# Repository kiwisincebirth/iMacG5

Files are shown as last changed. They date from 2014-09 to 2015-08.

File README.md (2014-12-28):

iMacG5
======

This is an Arduino (Leonardo) project that implements a System Management Controller on a Apple iMac that has been converted to a Hackintosh replacing the original G5 motherboard with an Intel Haswell NUC D54250. See the following for full details of the project:

http://www.tonymacx86.com/completed-mods/139633-kiwis-20-imac-i5.html

The software (and hardware) provide System management function including
 * Management of full power management lifecycle.
 * Control of shutdown of original G5 ATX PSU
 * Control of LCD backlight inverter brightness from Mac Menu widget
 * Control of screen Brightnes via Mac Menu application (via USB serial)
 * Fan Speed Control from internal temperature monitoring
 * Front Panel LED and Power Switch control

This repository contains
 * The full Bill of Materials for the Hardware
 * The source code for Arduino microcontroller
 * The source code for the Brightness Menu on the Mac

This application also has code to support capacative touch sensors as used by MacTester in his excellent iMac creations. Thanks for hs contribution to this project.

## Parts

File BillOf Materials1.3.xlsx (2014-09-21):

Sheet: Sheet1
DESCRIPTION
 | This is a BOM and design of SMC controller for iMac G5 20 innch conversion. See the following links
 | http://www.tonymacx86.com/completed-mods/139633-kiwis-20-imac-i5.html
 | http://www.tonymacx86.com/imac-mods/107859-kiwis-next-project-imac-g5.html
PARTS
 | ARDUINO MODULE
 |  | https://www.sparkfun.com/products/12640
 |  | The module also needs pins soldered to it so it can be inserted in the IC Socket
 |  | The 24 pin IC socket needs to be seperated into two halves as the module is wider than a standard 24 pin IC
 | SOUND MODULE
 |  | NOTE: The full ISD1820 Module is needed that includes the microphone to record the sound.
 |  | As the constructed board does not include the record capability. The chip must be programmed off board
 |  | The Sound Module must have the ISD Chip is a socket
 |  | An identical ROSC resistor must be installed on the Sound recorder module to achieve the same record speed
 | PAM 8403
 |  | This module can be purchased on eBay
 | HEATSINK
 |  | The heatsink also requires a TO220 Mounting kit that includes a mica flm, and plastic screw insert
 | TEMP SENSOR
 |  | http://datasheets.maximintegrated.com/en/ds/DS18B20.pdf
SOFTWARE
 | https://github.com/kiwisincebirth/iMacG5/tree/master/SourceCode/iMac_i5_Rev10
CHANGES
 | REV 1.1 Changes
 |  | - Additional comments on the sockets, documentation
 |  | - Cut Trace to D1 Connected PSU control to D5 (Post 123)
 |  | - Delete Q3,R10,R11, won't be used, D4 now unused (Post 126)
 |  | - Cut Trace , and Add Diode (D2) on PWR Switch to NUC (Post 126)
 | REV 1.2 Changes
 |  | - Moved R13 (not needed)
 | REV 1.3 Changes (DS18B20)
 |  | - Removed Jumper from A1 to J10
 |  | - Cut Trace from A3 to J11
 |  | - Added Jumper connecting both temp Inputs to D16
 |  | - Added R18 (4K7) pull-up resistor to J10 - J11
 |  | - Added Link from J10 to J11

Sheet: BOM
ID | PartNum | Description | Region
~~-~~ | ~~TMP36~~ | ~~Temperature Sensor connected to J10 (Not on Board)~~ | ~~TEMP~~
~~-~~ | ~~TMP36~~ | ~~Temperature Sensor connected to J11 (Not on Board)~~ | ~~TEMP~~
- | DS18B20 | Temperature Sensor connected to J10 (Not on Board) | TEMP
- | DS18B20 | Temperature Sensor connected to J11 (Not on Board) | TEMP
- | SPEAKER | Chime Speaker connected to J9 (Not On Board) | CHIME
C1 | 0.1uf | Capacator | FAN VOLTAGE
C2 | 10uf | Capacator | FAN VOLTAGE
C3 | 10uf | Capacator | FAN VOLTAGE
C4 | 100uf | Capacator (12V Supply) | POWER
C5 | 0.1uf | Capacator | ATX
C6 | 47uf | Capacator (3.3V Supply) | POWER
C7 | 0.1uf | Capacator (Switch Debounce) | MICRO
C8 | 0.1uf | Capacator (Power Noise Bypass) | MICRO
C9 | 47uf | Capacator (5V SBY Supply) | POWER
C10 | 47uf | Capacator (5V Supply) | POWER
D1 | 1N4007 | Power Diode | FAN VOLTAGE
D2 | 1N4148 | Signal Diode | NUC CONTROL
H1 | Heatsink | TO220 Heatsink (19 x 19 x 9.5mm) with mounting | FAN VOLTAGE
J1 | 6 Pin | Screw Terminal PCB Block (G5 ATX PSU) | POWER
J10 | 3Pin | PCB Header (Temperature Sensor TMP36) | TEMP
J11 | 3Pin | PCB Header (Temperature Sensor TMP36) | TEMP
J12 | 3Pin | PCB Horizontal Header (NUC Motherboard) | MOTHER
J14 | 1Pin | PCB Header (Inverter Brightness) | INVERTER
J15 | 2 Pin | PCB Header (Capacative Touch Input) | CAPACITANCE
J16 | 2 Pin | PCB Header (Capacative Touch Input) | CAPACITANCE
J17 | 3Pin | PCB Header (Front Panel LED and Switch) | FRONT PANEL
J18 | 3 Pin | PCB Header (Audio Input from NUC) | AMPLIFIER
J2 | 24 Pin | IC Socket (Arduino) | MICRO
J3 | 14 Pin | IC Socket (ISD 1820) | CHIME
J4 | 7 Pin | PCB Header Socket (Amplifier Module) | AMPLIFIER
J5 | 4 Pin | PCB Header (iMac G5 Case Fan) | FAN VOLTAGE
J6 | 6 Pin | 3 x 2row PCB Header (iMac G5 Case Fan) | FAN VOLTAGE
J7 | 6 Pin | 3 x 2row PCB Header (iMac G5 Lower Case Fan) | FAN VOLTAGE
J8 | 2Pin | PCB Header (Main LCD 12V Source) | POWER
J9 | 3 Pin | PCB Header (Chime Speaker) | CHIME
LED1 | LED | LED (5V Power Indicator) | POWER
M3 | 2N7000 | Mosfett Transistor | FAN VOLTAGE
Q1 | 2N3904 | NPN Transistor | INVERTER
Q2 | 2N3906 | PNP Transistor | ATX
~~Q3~~ | ~~2N3904~~ | ~~NPN Transistor~~ | ~~FRONT PANEL~~
Q4 | 2N3904 | NPN Transistor | FRONT PANEL
R1 | 330ohm | 1/4 w Resistor | FAN VOLTAGE
~~R10~~ | ~~10Kohm~~ | ~~1/4 w Resistor~~ | ~~FRONT PANEL~~
~~R11~~ | ~~4.7Kohm~~ | ~~1/4 w Resistor~~ | ~~FRONT PANEL~~
R12 | 240ohm | 1/4 w Resistor (Calibrate for Front Panel LED) | FRONT PANEL
R13 | 240ohm | 1/4 w Resistor (Calibrate for LED1) | POWER
R14 | 1Mohm | 1/4 w Resistor | CAPACITANCE
R15 | 1Mohm | 1/4 w Resistor | CAPACITANCE
R16 | 8K2ohm | 1/4 w Resistor (Voltage Divider) | CHIME
R17 | 15Kohm | 1/4 w Resistor (Voltage Divider) | CHIME
R18 | 4K7ohm | 1/4 w Resistor | TEMP
R2a | 330ohm | 1/4 w Resistor | FAN VOLTAGE
R2b | 4K7ohm | 1/4 w Resistor | FAN VOLTAGE
R3 | 2Kohm | 1/4 w Resistor | FAN VOLTAGE
R4 | 2Kohm | 1/4 w Resistor | FAN VOLTAGE
R5 | 10Kohm | 1/4 w Resistor | INVERTER
R6 | 4K7ohm | 1/4 w Resistor | INVERTER
R7 | 1K5ohm | 1/4 w Resistor | INVERTER
R8 | 4K7ohm | 1/4 w Resistor | ATX
R9 | 10ohm | 1/2 w Resistor | ATX
ROSC | 82Kohm | 1/4 w Resistor | CHIME
SW1 | SPST | PCB Micro Pushbutton Switch (Reset) | MICRO
U1 | Arduino | Sparkfun Arduino Pro Micro 16MHz 5V | MICRO
U2 | LM317 | Variable Voltage Regulator | FAN VOLTAGE
U3 | ISD1820 | Sound Recorder Playback IC | CHIME
U4 | PAM 8403 | 3W x 2 Amplifier Module with Vol Adjust | AMPLIFIER

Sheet: FRONT
NOTE R10 R11 and Q3 have been removed from this Circuit

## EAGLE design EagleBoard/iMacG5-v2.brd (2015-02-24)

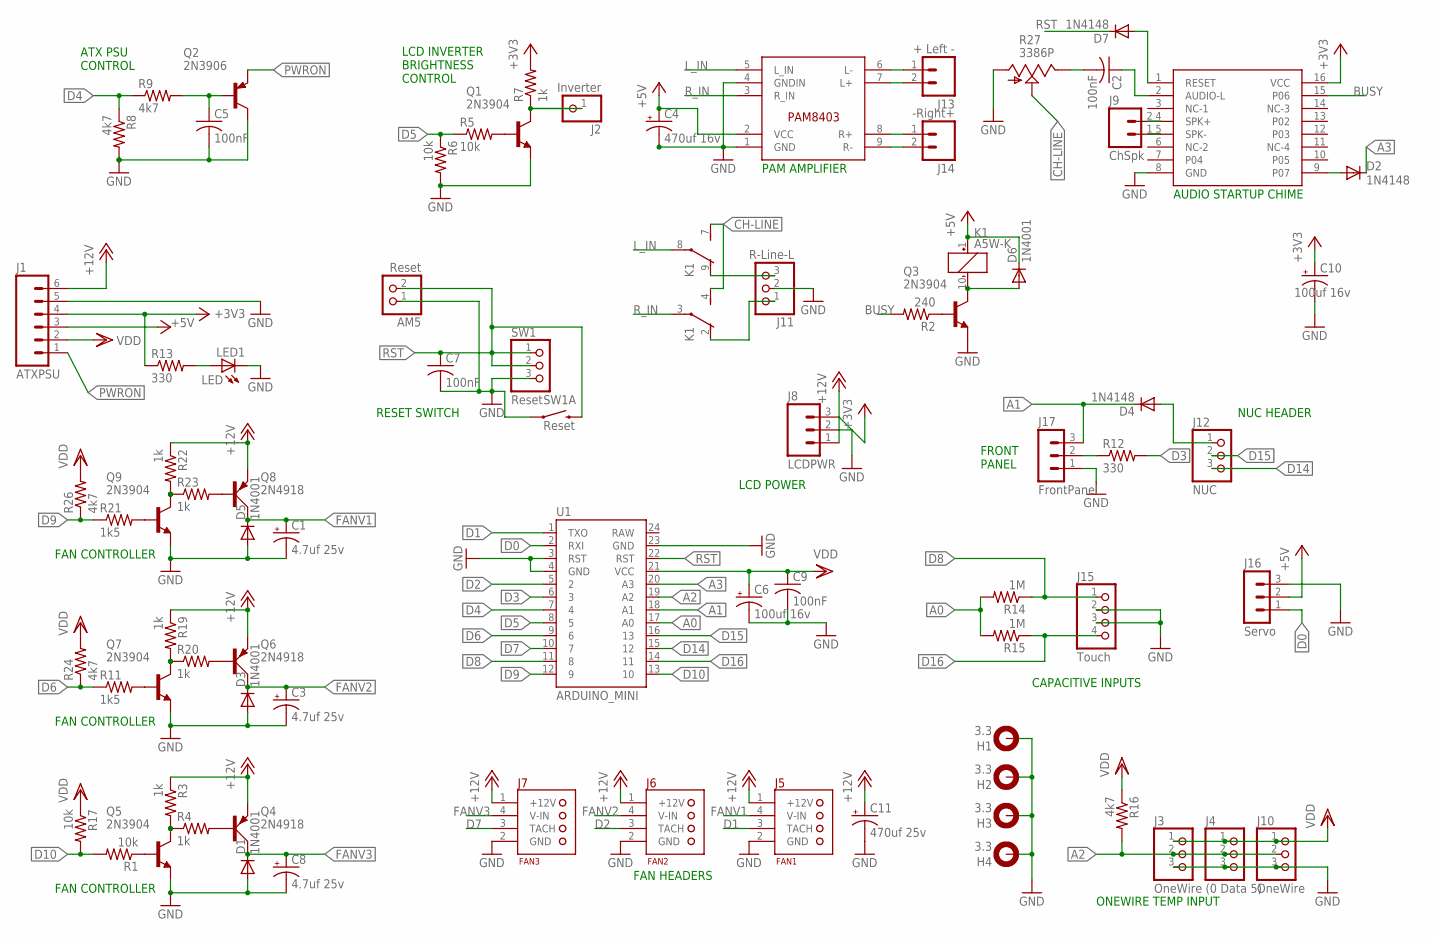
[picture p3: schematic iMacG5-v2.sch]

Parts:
AM5: Reset; 1X02
C1, C3, C8: 4.7uf 25v; E2,5-5
C2, C5, C7, C9: 100nF; C050-024X044
C4: 470uf 16v; E3,5-8
C6, C10: 100uf 16v; E2,5-5
C11: 470uf 25v; E3,5-8
D1, D3, D5: 1N4001; D-2.5
D2, D4: 1N4148; D-2.5
D6: 1N4001; D-7.5
D7: 1N4148; DO35-7
H1, H2, H3, H4: 3.3; 3,3-PAD
J1: ATXPSU; MOLEX-1X6
J2: Inverter; 1X01
J3, J10: OneWire; 1X03
J4: (0 Data 5); 1X03
J5: FAN1; MOLEX-1X4
J6: FAN2; IMAC_G5_2X3
J7: FAN3; IMAC_G5_2X3
J8: LCDPWR; MOLEX-1X3
J9: ChSpk; MOLEX-1X2
J11: R-Line-L; 1X03
J12: NUC; 1X03
J13: + Left -; MOLEX-1X2
J14: -Right+; MOLEX-1X2
J15: Touch; 1X04
J16: Servo; MA03-1
J17: FrontPanel; MA03-1
K1: A5W-K; TQ2
LED1: LED; LED3MM
Q1, Q3, Q5, Q7, Q9: 2N3904; TO92
Q2: 2N3906; TO92
Q4, Q6, Q8: 2N4918; TO126AV
R1, R17: 10k; 0207/7
R2: 240; 0207/2V
R3, R4, R7, R19, R20, R22, R23: 1k; 0207/2V
R5, R6: 10k; 0207/2V
R8, R9, R24, R26: 4k7; 0207/2V
R11, R21: 1k5; 0207/2V
R12, R13: 330; 0207/2V
R14, R15: 1M; 0207/7
R16: 4k7; 0207/7
R27: 3386P; B25P
SW1: Reset; 1X03
SW1A: Reset; TACTILE-PTH
U1: ARDUINO_MINI
U2: PAM8403
U3: WTV020-SD-16P

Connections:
+3V3: C10.+, J1.4, J8.3, R7.2, R13.1, U3.16 (VCC)
+5V: C4.+, D6.C, J1.3, J16.2, K1.1 (+), U2.2 (VCC)
+12V: C11.+, J1.6, J5.1 (+12V), J6.1 (+12V), J7.1 (+12V), J8.1, Q4.E, Q6.E, Q8.E, R3.1, R19.1, R22.1
A0: R14.2, R15.2, U1.17 (A0)
A1: D4.C, J17.3, U1.18 (A1)
A2: J3.2, J4.2, J10.2, R16.2, U1.19 (A2)
A3: D2.C, U1.20 (A3)
BUSY: R2.2, U3.15 (P06)
CH-LINE: K1.4 (S), K1.7 (S), R27.S
D0: J16.1, U1.2 (RXI)
D1: J5.3 (TACH), U1.1 (TXO)
D2: J6.3 (TACH), U1.5 (2)
D3: R12.2, U1.6 (3)
D4: R8.1, R9.1, U1.7 (4)
D5: R5.1, R6.1, U1.8 (5)
D6: R11.1, R24.1, U1.9 (6)
D7: J7.3 (TACH), U1.10 (7)
D8: J15.1, R14.1, U1.11 (8)
D9: R21.1, R26.1, U1.12 (9)
D10: R1.2, R17.2, U1.13 (10)
D14: J12.3, U1.15 (12)
D15: J12.2, U1.16 (13)
D16: J15.4, R15.1, U1.14 (11)
FANV1: C1.+, D5.C, J5.4 (V-IN), Q8.C
FANV2: C3.+, D3.C, J6.4 (V-IN), Q6.C
FANV3: C8.+, D1.C, J7.4 (V-IN), Q4.C
GND: AM5.1, C1.-, C3.-, C4.-, C5.2, C6.-, C7.2, C8.-, C9.2, C10.-, C11.-, D1.A, D3.A, D5.A, H1.B3,3, H2.B3,3, H3.B3,3, H4.B3,3, J1.5, J3.3, J4.3, J5.2 (GND), J6.2 (GND), J7.2 (GND), J8.2, J10.3, J11.2, J15.2, J15.3, J16.3, J17.1, LED1.K (C), Q1.3 (E), Q2.1 (C), Q3.3 (E), Q5.3 (E), Q7.3 (E), Q9.3 (E), R6.2, R8.2, R27.A, SW1.3, SW1A.1, U1.3 (RST), U1.4 (GND), U1.23 (GND), U2.1 (GND), U2.4 (GNDIN), U3.8 (GND)
L_IN: K1.8, U2.5 (L_IN)
unnamed: D4.A, J12.1
unnamed: D6.A, K1.10 (-), Q3.1 (C)
unnamed: Q1.2 (B), R5.2
unnamed: Q4.B, R4.2
unnamed: Q5.1 (C), R3.2, R4.1
unnamed: J2.1, Q1.1 (C), R7.1
unnamed: J9.1, U3.5 (SPK-)
unnamed: J9.2, U3.4 (SPK+)
unnamed: J17.2, R12.1
unnamed: J14.1, U2.8 (R+)
unnamed: D7.A, U3.1 (RESET)
unnamed: C2.2, R27.E
unnamed: J14.2, U2.9 (R-)
unnamed: Q5.2 (B), R1.1
unnamed: J13.2, U2.7 (L+)
unnamed: Q6.B, R20.2
unnamed: LED1.A, R13.2
unnamed: J11.3, K1.9 (O)
unnamed: J11.1, K1.2 (O)
unnamed: Q3.2 (B), R2.1
unnamed: D2.A, U3.9 (P07)
unnamed: J13.1, U2.6 (L-)
unnamed: Q7.1 (C), R19.2, R20.1
unnamed: Q7.2 (B), R11.2
unnamed: Q8.B, R23.2
unnamed: Q9.1 (C), R22.2, R23.1
unnamed: Q9.2 (B), R21.2
unnamed: C5.1, Q2.2 (B), R9.2
unnamed: C2.1, U3.2 (AUDIO-L)
PWRON: J1.1, Q2.3 (E)
RST: AM5.2, C7.1, D7.C, SW1.1, SW1.2, SW1A.3 (2), U1.22 (RST)
R_IN: K1.3, U2.3 (R_IN)
VDD: C6.+, C9.1, J1.2, J3.1, J4.1, J10.1, R16.1, R17.1, R24.2, R26.2, U1.21 (VCC)

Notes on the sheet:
FAN HEADERS
PAM AMPLIFIER
CAPACITIVE INPUTS
AUDIO STARTUP CHIME
FAN CONTROLLER
NUC HEADER
FRONT PANEL
ONEWIRE TEMP INPUT
LCD INVERTER BRIGHTNESS CONTROL
ATX PSU CONTROL
RESET SWITCH
LCD POWER

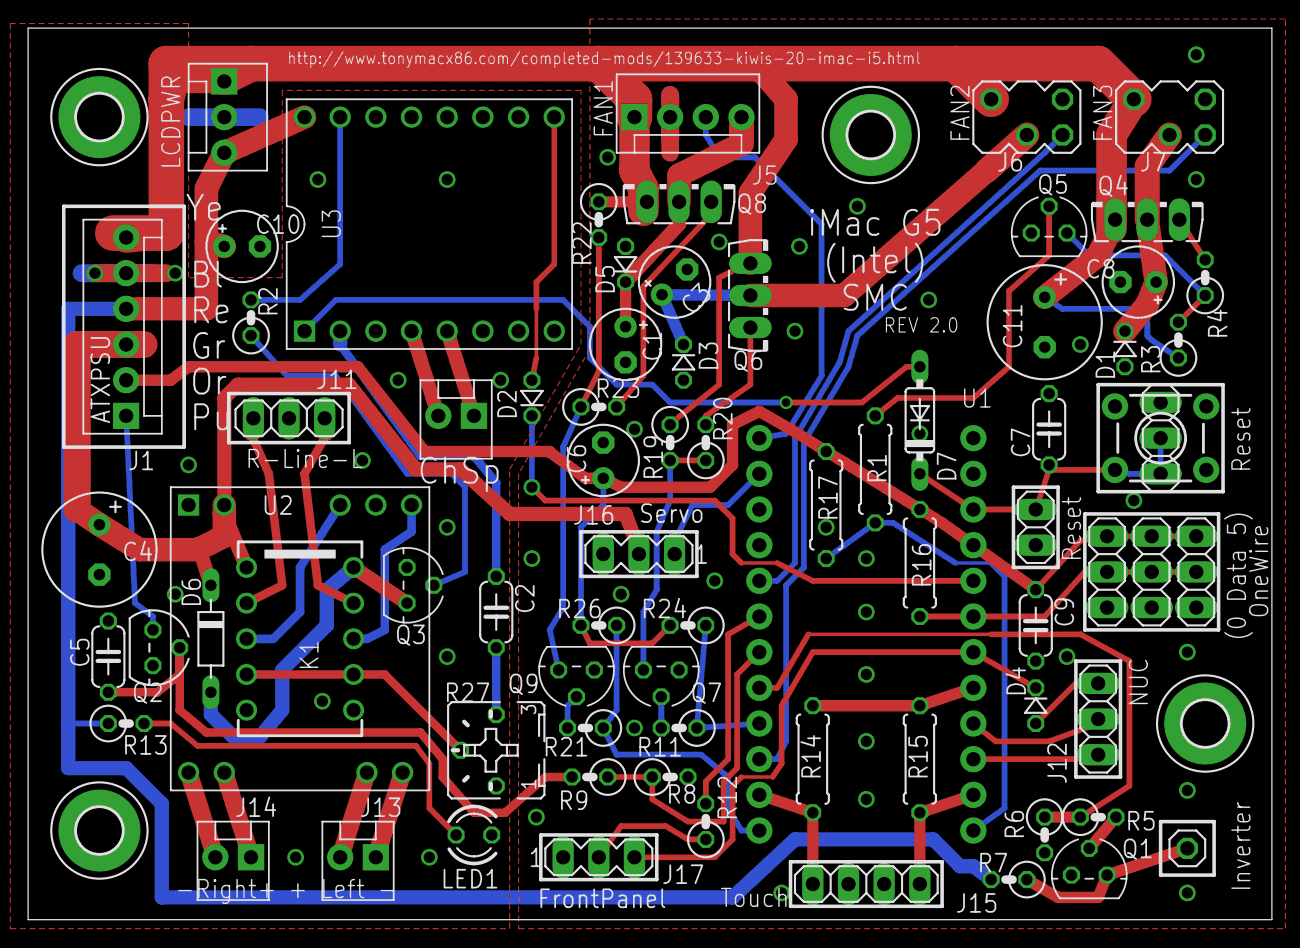
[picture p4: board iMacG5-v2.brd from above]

Board: 2 copper layers, 88.6 x 63.5 mm, 80 parts (0 on the bottom side), 61 nets.

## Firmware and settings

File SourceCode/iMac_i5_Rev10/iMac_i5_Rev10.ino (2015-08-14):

// BOF preprocessor bug prevent - insert me on top of your arduino-code
// See: http://subethasoftware.com/2013/04/09/arduino-compiler-problem-with-ifdefs-solved/
#if 1
__asm volatile ("nop");
#endif

/**
 * System Management Controller Kiwi's iMac G5
 * 
 * Description : Provides System management function for iMac G5, providing 
 *   fuctionality for Power Management for G5 internl PSU, and Intel NUC Motherboard. 
 *   Also provides control of Inverter Brightnes and Fan Speed Control, and permits 
 *   control via USB for applications that wish to control these functions 
 *   e.g. screen brightness.
 *
 * This application also has code to support capacative touch sensors as used 
 * by MacTester in his excellent iMac creations
 *
 * See : http://www.tonymacx86.com/imac-mods/107859-kiwis-next-project-imac-g5.html
 * Source Repository : https://github.com/kiwisincebirth/iMacG5/tree/master/SourceCode
 * Platform : Arduino Leonardo ATMega32U4
 * Author : KiwiSinceBirth
 * Contributions : MacTester (capacitance)
 * Written : July 2014
 */

//#define DEBUG // enables debig mode
//#define LEGACYBOARD // supports the legacy fan control LM317 voltage, proto board  
//#define LEGACY-RPM // Legacy Controlled by RPM Inputs, not LM317 Voltage feedback
#define COMMANDABLE // has all commands not just brightness
//#define CAPACITIVE // support for cap touch sensors
#define TEMPERATURE // temperature intput for fans

#include <DebugUtils.h>
#include <PWMFrequency.h>
#include <SimpleTimer.h>
#include <FiniteStateMachine.h>

#include <EEPROMex.h>
#include <EEPROMVar.h>
// NOTE: Please remove the "_EEPROMEX_DEBUG" 
// #define in the source code of the library

#ifdef CAPACITIVE
#include <CapacitiveSensorDue.h>
#endif

#ifdef TEMPERATURE
#include <OneWire.h>
#include <DallasTemperature.h>
#endif

/**
 * The Libraries: DebugUtils, FSM, PWMFrequency, SimpleTimer can be obtained here
 * https://github.com/kiwisincebirth/Arduino/tree/master/Libraries
 *
 * And the following libraries come from here
 * EEPROMEx - https://github.com/thijse/Arduino-Libraries/tree/master/EEPROMEx
 * CapacitiveSensorDue - https://github.com/arduino-libraries/CapacitiveSensor/tree/master/libraries
 * OneWire - http://www.pjrc.com/teensy/td_libs_OneWire.html
 * DallasTemperature - https://github.com/milesburton/Arduino-Temperature-Control-Library
 */

//
// ---------------------
// CONSTANTS
// ---------------------
//

// time before transition is effective (input debounce)
#define POWER_STATE_TRANSITION_TIME 50

// the amount of time to wait after acivation of Main Power before pressing NUC switch
#define NUC_POWER_SWITCH_WAIT_TIME 1000

// The amount of time the NUC Power switch is depressed
#define NUC_POWER_SWITCH_ACTIVATION_TIME 100

// The amount of time the Chime switch is depressed
#define CHIME_ACTIVATION_TIME 100

// Amount of Time the Front panel LED takes to Fade Up
#define LED_FADE_UP_TIME_WARM_BOOT 5000
#define LED_FADE_UP_TIME_COLD_BOOT 10000

// when starting up, if transition takes longer then move to shutdown
#define STARTUP_TIMEOUT_BEFORE_SHUTDOWN 10000

// Cycle time for Sleep LED Breathing
#define LED_BREATH_CYCLE_TIME 5000

// time after shutdown the ATX PSU is turned off.
#define ATX_PSU_SHUTDOWN_TIMOUT 30000

// time interval that Temperatures are sampled, and fan targets are set.
#define TEMPERATURE_SAMPLE_PERIOD 30000

// time intervale to attempt write of Brightness to EEPROM, burnout protection
#define EEPROM_BRIGHTNESS_PERIOD 120000

// amount of times the sensor is read
#define CAPACITIVE_SENSOR_READ_PERIOD 300

// time between capacitive recalibration - 10 minutes
#define CAPACITIVE_RECALIBRATE_PERIOD 600000

// Some important constants
//#define SERIAL_BAUD_RATE 9600
#define SERIAL_BAUD_RATE 115200

// ---------------------

// Some ASCII Constancts
#define CR 13
#define LF 10
#define TAB '\t'
#define STOP ','
#define COMMA ','
#define COLON ':'
#define EQUALS '='
#define ZERO '0'
#define DEGC " °C" // DEGC " degC"
#define RPM " RPM"

//
// ================
// REVISION HISTORY
// ================
// 1.0 - 26/07/2014 - Initial Stable Feature complete Release
// 1.1 - 31/01/2015 - Added support for RPM Fan Input, future feature
// 1.1 - 31/01/2015 - Simplified EEPROM Code, Long support Only.
// 1.1 - 31/01/2015 - Added addition ifdefs to reduce size of bnary.
// 1.2 - 15/02/2015 - Started to add support for RPM Fan Control
// 1.3 - 19/04/2015 - Added Support for Mac Testers Slider App, Temps, 115200, OK
// 1.4 - 331/6/2015 - Added final support for MacTesters Slider App
//
// --------------
// Future Futures
// --------------
// Better Capacitance Calibration Routines, that ask user to touch sensor, then measure
// If brightness change by Capacatance report report back to the app, so slider can moved
//

//
// ===================
// PIN ASSIGNMENTS
// ===================
//

//
// Digital 0, 1, Shared as serial pins (Serial1)
// Digital 2 - 13, General Purpuse 
// Digital 3, 5, 6, 9, 10, 11, and 13 - PWM
// Digital 11 - 13 Excluded on Pro Micro
// Digital 13 has (not Leo) an LED and resistor attached to it
// Digital 14 - 16, Shared with a SPI bus
// Digital 17 - Doubles and RX LED
// Digital Pins can sink 40ma, recommended 470 ohm resistor
// Analog Inputs: A0-A3, Pro Micro excludes A4, A5
// Analog Inputs: A6-A11 (on digital pins 4, 6, 8, 9, 10, and 12)
// Analog Pins can be used a digital ( refer to them as A0, A1, ...)
//

#ifdef LEGACYBOARD

//
// LEGACY PINS
//

// -------------- POWER DETECTION CONTROL

// Power Switch Control Pins
#define POWER_SWITCH_PIN_POUT 3 
 
// Main PSU Control to de-active ATX PSU
#define PSU_DEACTIVATE_POUT 5

// Power Notification
#define SLEEP_LED_POUT 6

// Pwer State Sense Pins
#define NUC_POWER_LED_VCC_PIN 14
#define NUC_POWER_LED_GND_PIN 15

// ---------------------- FAN VOLTAGE INPUT

// Fan Voltage Input Analog Detection
#define FAN_OUTPUT_AIN A2

// NUMBER OF FAN NPUTS
#define FAN_COUNT 2

// The Pins For Fan Input
const byte FAN_RPM_PIN[] = { 0, 1 }; 

// Interrupts that fans are attached to.
#define FAN1_INTERRUPT 2 
#define FAN2_INTERRUPT 3 

// --------------------- FAN CONTROL

#ifdef LEGACY-RPM

// Time between controlling the Fans
#define FAN_CONTROL_PERIOD 5000

#else

// Time between controlling the Fans
#define FAN_CONTROL_PERIOD 100

#endif

// Number of Output Fan Control PWM's
#define FAN_CONTROL_COUNT 1

// PWM Fan Speed Voltage OUTPUT
const byte FAN_CONTROL_PWM[] = { 9 } ;

// Prescale Values for controlling PWM
const int FAN_CONTROL_PWM_PRESCALE[] = {1};

#ifdef LEGACY-RPM

// Values in RPM
#define OFF_FAN_VALUE 100
#define MIN_FAN_VALUE 1200
#define MAX_FAN_VALUE 5000

#else

// Values in Millivolts
#define OFF_FAN_VALUE 100
#define MIN_FAN_VALUE 330
#define MAX_FAN_VALUE 1200

#endif

// -------------------- TEMPS 

// Digital Pin For Temps
#define TEMP_PIN 16

// -------------------- INVERTER 

// Inverter Brigtness PWM Out
#define INVERTER_PWM 10 

// --------------------- CAP TOUCH

// Up and down capacitive touch broghtness pins
#define TOUCH_COMMON_PIN_CAP 2
#define TOUCH_DOWN_PIN_CAP 7
#define TOUCH_UP_PIN_CAP 8

// -------------------- CHIME

// Chime Output --->>>  HIGH <<<---  Level OUTPUT
#define CHIME_POUT 1

#else

//
//
// MODERN PINS
//
//

// -------------- POWER DETECTION CONTROL

// Power Switch Control Pins
#define POWER_SWITCH_PIN_POUT A1
 
// Main PSU Control to de-active ATX PSU
#define PSU_DEACTIVATE_POUT 4

// Power Notification
#define SLEEP_LED_POUT 3

// Pwer State Sense Pins
#define NUC_POWER_LED_VCC_PIN 14
#define NUC_POWER_LED_GND_PIN 15

// ---------------------- FAN SPEED PINS

// NUMBER OF FAN NPUTS
#define FAN_COUNT 3

// The Pins For Fan Input
const byte FAN_RPM_PIN[] = { 1, 2, 7 }; 

// Interrupts that fans are attached to.
#define FAN1_INTERRUPT 3 
#define FAN2_INTERRUPT 1 
#define FAN3_INTERRUPT 4 

// --------------------- FAN CONTROL

// Time between controlling the Fans
#define FAN_CONTROL_PERIOD 5000

// Number of Output Fan Control PWM's
#define FAN_CONTROL_COUNT 3

// Fan Control Outputs
const byte FAN_CONTROL_PWM[] = { 9, 6, 10 } ;

// Prescale Values for controlling PWM
const int FAN_CONTROL_PWM_PRESCALE[] = { 256, 256, 256 };

// Values in RPM
#define OFF_FAN_VALUE 0
#define MIN_FAN_VALUE 1200
#define MAX_FAN_VALUE 4000

// -------------------- TEMPS 

// Digital Pin For Temps
#define TEMP_PIN A2

// -------------------- INVERTER 

// Inverter Brigtness PWM Out
#define INVERTER_PWM 5 

// --------------------- CAP TOUCH

// Up and down capacitive touch broghtness pins
#define TOUCH_COMMON_PIN_CAP A0
#define TOUCH_DOWN_PIN_CAP 16
#define TOUCH_UP_PIN_CAP 8

// -------------------- CHIME

// Chime Output LOW Level OUTPUT
#define CHIME_POUT A3

#endif

//
// ================================================
// EEPROM Locations that configuratyion data is stored
// ==================================================
//

// Location the Current Version ID is stored
#define EEP_VERSION 0

#define EEP_BRIGHT 1 // brghtness Setting 0 - 100 %
#define EEP_CYC_SMC 2 // SMC Power / Rest Cycles (StartUp)
#define EEP_CYC_POWER 3 // CPU Power Cycles (Power Up)
#define EEP_CYC_SLEEP 4 // CPU Sleep Cycles (Wake)
#define EEP_TIM_SYSTEM 5 // System Uptime
#define EEP_TIM_LCD 6 //LCD Power On Time
#define EEP_TIM_SLEEP 7 //LCD Power On Time

#define EEP_RESERVED3 8 
#define EEP_RESERVED4 9 
#define EEP_RESERVED5 10 
#define EEP_RESERVED6 11 
#define EEP_RESERVED7 12 
#define EEP_RESERVED8 13 
#define EEP_RESERVED9 14 
#define EEP_RESERVEDA 15 

#define EEP_MIN_BRIGHT 16 // Minimum PWM for Inverter - When Brihhtness is 0%
#define EEP_MAX_BRIGHT 17 // Maximum PWM for Inverter - When Brightness is 100%
#define EEP_BRIGHT_INC 18 // Number of percent brightness Increased or decreased
#define EEP_MIN_TEMP 19 // Fan Control to Map Temp to Voltage
#define EEP_MAX_TEMP 20 // Fan Control to Map Temp to Voltage
#define EEP_MIN_VOLT_RPM 21 // Fan Control to Map Temp to Voltage / RPM
#define EEP_MAX_VOLT_RPM 22 // Fan Control to Map Temp to Voltage / RPM
#define EEP_DN_CAP_THR 23 // Capacatance Treshold for Down Button
#define EEP_UP_CAP_THR 24 // Capacatance Treshold for Up Button
#define EEP_CAP_SAMPLE 25 // Number of Samples for Capacatance
#define EEP_DEPRECATED1 26 // The Old Model ID of the project this board implements
#define EEP_MIN_LED_PWM 27 // Minimum PWM Value for Front Panel LED Effects
#define EEP_MAX_LED_PWM 28 // Maximum PWM Value for Front Panel LED Effects
#define EEP_INVERTER_STARTUP_DELAY 29 // milliseconds before starting inverter 
#define EEP_CAP_CONTROL 30 // is the capacatace controller enabled 
#define EEP_FAN_CONTROL 31 // is the fan temp controller enabled  
#define EEP_INVERTER_WARM_DELAY 32 // milliseconds before starting inverter 

//
// Names of Data stored in these locations
//

const char PROGMEM string_RES[] PROGMEM = "Reserved";
const char PROGMEM string_DEP[] PROGMEM = "Deprecated";
const char PROGMEM string_VS[] PROGMEM = "Version-Size";
const char PROGMEM string_P0[] PROGMEM = "Bright-%";
const char PROGMEM string_P1[] PROGMEM = "Cycles-SMC";
const char PROGMEM string_P2[] PROGMEM = "Cycles-Power";
const char PROGMEM string_P3[] PROGMEM = "Cycles-Sleep";
const char PROGMEM string_P4[] PROGMEM = "Time-Power";
const char PROGMEM string_P5[] PROGMEM = "Time-LCD";
const char PROGMEM string_P6[] PROGMEM = "Time-Sleep";

const char PROGMEM string_02[] PROGMEM = "MinBright-PWM"; 
const char PROGMEM string_03[] PROGMEM = "MaxBright-PWM"; 
const char PROGMEM string_04[] PROGMEM = "BrightInc-%";
const char PROGMEM string_05[] PROGMEM = "MinTemp-.01c"; 
const char PROGMEM string_06[] PROGMEM = "MaxTemp-.01c";
#ifdef LEGACYBOARD
  #ifdef LEGACY-RPM
const char PROGMEM string_07[] PROGMEM = "MinRPM    "; // redefined to be RPM Range for the Fans
const char PROGMEM string_08[] PROGMEM = "MaxRPM    ";
  #else
const char PROGMEM string_07[] PROGMEM = "MinVolt-.01v";
const char PROGMEM string_08[] PROGMEM = "MaxVolt-.01v";
  #endif
#else
const char PROGMEM string_07[] PROGMEM = "MinRPM    "; // redefined to be RPM Range for the Fans
const char PROGMEM string_08[] PROGMEM = "MaxRPM    ";
#endif
const char PROGMEM string_09[] PROGMEM = "CapDnThresh"; 
const char PROGMEM string_10[] PROGMEM = "CapUpThresh";
const char PROGMEM string_11[] PROGMEM = "CapSamples";
const char PROGMEM string_13[] PROGMEM = "MinLED-PWM";
const char PROGMEM string_14[] PROGMEM = "MaxLED-PWM";  
const char PROGMEM string_15[] PROGMEM = "InvertStartDly";  
const char PROGMEM string_16[] PROGMEM = "CapBrigEnabled"; 
const char PROGMEM string_17[] PROGMEM = "FanTempEnabled"; 
const char PROGMEM string_18[] PROGMEM = "InvertWarmDly"; 

//
// the following must contain all strings from above
//

PGM_P const eepName[] PROGMEM = {
//const char PROGMEM *eepName[] = {  // older 1.0.x
  string_VS, string_P0, string_P1, string_P2, string_P3, string_P4, string_P5, string_P6, 
  string_RES, string_RES, string_RES, string_RES, string_RES, string_RES, string_RES, string_RES, 
  string_02, string_03, string_04, string_05, string_06, string_07, 
  string_08, string_09, string_10, string_11, string_DEP, string_13, 
  string_14, string_15, string_16, string_17, string_18 };

// 
// ========================================
// MAIN ARDUINO SETUP (1x during startup)
// ========================================
//

void setup () {
  
  // ensure basic configuration of user data is carried out.
  checkEepromConfiguration();
}

// 
// ========================================
// MAIN ARDUINO LOOP (Called Repeatidly)
// ========================================
//

void loop () {

  // allow the FSM to interpret and process state transitions
  loopFiniteStateMachine();

  // Let the simple timer run any backgound tasks
  loopSimpleTimer();

  // handles user input command received from serial port 
  loopSerialCommandProcessor();
}

//
// ============================================
// EEPRORM SETUP AND USER CONFIGURATION
// ============================================
//

/**
 * Setup the device if not initialised, flasing the eeprom with defaults, if they dont exist
 */
void checkEepromConfiguration() {

  // The version number holds the number of the highest value stored in eeprom
  // This allows future software upgrades with new eeprom values, to have defaults
  // written to the eeprom without overitting exisitng values that are stored there
  // VERSION = The Numer of (the highest) items that already have values, dont overitte
  
  // Read the current version of the eeprom
  byte currentHighest = eepromRead(EEP_VERSION);
  if ( currentHighest == 255 ) currentHighest = 0;

  // All The Deefault Values
  if ( currentHighest < EEP_INVERTER_WARM_DELAY ) { 
    
    // write default values
    eepromWrite( EEP_BRIGHT, 100 ); // 100% brightness
    eepromWrite( EEP_CYC_SMC, 0);   // 
    eepromWrite( EEP_CYC_POWER, 0); // 
    eepromWrite( EEP_CYC_SLEEP, 0); // 
    eepromWrite( EEP_TIM_SYSTEM, 0); // 
    eepromWrite( EEP_TIM_LCD, 0); // 
    eepromWrite( EEP_TIM_SLEEP, 0); // 
    eepromWrite( EEP_RESERVED3, 0); // 
    eepromWrite( EEP_RESERVED4, 0); // 
    eepromWrite( EEP_RESERVED5, 0); // 
    eepromWrite( EEP_RESERVED6, 0); // 
    eepromWrite( EEP_RESERVED7, 0); // 
    eepromWrite( EEP_RESERVED8, 0); // 
    eepromWrite( EEP_RESERVED9, 0); // 
    eepromWrite( EEP_RESERVEDA, 0); // 
    eepromWrite( EEP_MIN_BRIGHT, 60 ); // PWM
    eepromWrite( EEP_MAX_BRIGHT, 255 ); // PWM
    eepromWrite( EEP_BRIGHT_INC, 5 ); // Brightness Increme
    eepromWrite( EEP_MIN_TEMP, 0 ); // 100ths of a dreee e.g. 2000 = 20.0 degrees
    eepromWrite( EEP_MAX_TEMP, 2000 ); // 100ths of a dreee
    eepromWrite( EEP_MIN_VOLT_RPM, 250 ); // 100ths of a volt e.g. 330 = 3.3V
    eepromWrite( EEP_MAX_VOLT_RPM, 550 ); // 100ths of a volt
    eepromWrite( EEP_DN_CAP_THR, 150 ); // Down Threashhold
    eepromWrite( EEP_UP_CAP_THR, 150 ); // Up Threashold
    eepromWrite( EEP_CAP_SAMPLE, 200 ); // Samples
    eepromWrite( EEP_DEPRECATED1, 0 ); // Was Old Default Model ID
    eepromWrite( EEP_MIN_LED_PWM, 5 ); // Minimum Effects PWM for Front Panel LED
    eepromWrite( EEP_MAX_LED_PWM, 255 ); // Maximum Effects PWM for Front Panel LED
    eepromWrite( EEP_INVERTER_STARTUP_DELAY, 6000 ); // COLD Inverter Startup delay miliseconds
    eepromWrite( EEP_CAP_CONTROL, 0 ); // Maximum Effects PWM for Front Panel LED
    eepromWrite( EEP_FAN_CONTROL, 1 ); // Inverter Startup delay miliseconds
    eepromWrite( EEP_INVERTER_WARM_DELAY, 6000 ); // WARM Inverter Startup delay miliseconds

    // and version number
    currentHighest = EEP_INVERTER_WARM_DELAY;
  } 

  // finally update eprom with Highest numbered item stored in EEPROM
  eepromWrite(EEP_VERSION,currentHighest);
}

//----------------------------- PUBLIC

long eepromRead(byte location) {
  
  // Can write to an invalid location 
  if (isLocationException(location) ) return -1;

  return EEPROM.readLong( eepromLocation(location) );
}

int eepromWrite(byte location, long value) {

  // Can write to an invalid location 
  if (isLocationException(location) ) return -1;

  // the eeprom library protects from wrinting same values
  return EEPROM.updateLong( eepromLocation(location), value );
}

void inline incrementCounter(byte location) {
  addToCounter(location, 1);
}

void addToCounter(byte location,unsigned long value) {
  eepromWrite(location, eepromRead(location)+value);
}

// ------------------ PRIVATE

byte sizeofEeprom() {
  return EEP_INVERTER_WARM_DELAY + 1; // HARD COCDED
}

boolean isLocationException(byte location) {

  if (location >= sizeofEeprom() ) {
    return true;
  }
  return false;
}

boolean isProtectedException(byte location) {
  return location < 16;
}

int inline eepromLocation(byte location) {
  return location * 4;
}

String eepromName(byte location) {
  static char buffer[20]; 
  if (isLocationException(location) ) return "";
  strcpy_P(buffer, (char*)pgm_read_word(&(eepName[location])) ); 
  return buffer;
}

// -------------------------------

#ifdef COMMANDABLE

/**
 * Process a command from the serial port
 */
void processCommandEeprom(String subCmd, String extraCmd) {
  
  if (subCmd.equals("R")) {
    // EEPROM Read
    eepromReadCommand(extraCmd);
    
  } else if (subCmd.equals("W")) {
    // EEPROM Write EWnnn,xxxxx where n is the address and xxxx is the value
    eepromWriteCommand(extraCmd);
        
  } else if (subCmd.equals("F")) {
    // Reset The eeprom firmware version and reinit.
    eepromInitCommand();
    
  } else {
    Serial.println(F("Eprom Command Unknown: ERn (read), EWn,v (write), EF (factory)"));
  }
}

/**
 * Te Read EEPROM command can be passed an optional argument
 * n - which specifies the location to read, rather than iterating all locations.
 */
void eepromReadCommand(String extraCmd) {

  // if parameter passed then convert
  byte location = extraCmd.toInt();
  if (location>0 && !isLocationException(location) ) {
    eepromReadCommand(location);
  } else {
    for (byte i = 0;i<sizeofEeprom();i++) {
      eepromReadCommand(i);
    }
  }
}

void eepromReadCommand(byte location) {
  
  Serial.print(location);
  Serial.print(TAB);
  
  Serial.print(eepromName(location));
  Serial.print(TAB);
  
  Serial.println(eepromRead(location));
}

/**
 * The Write command has the following syntax
 * EWn,v - e,g EW7,3000  - writes the value of 3000 to address 7
 * Note: Some locations are protected, so cannot be written
 */
void eepromWriteCommand(String extraCmd) {
  
  // look for comma.
  byte index = extraCmd.indexOf(COMMA);
  if (index<=0) {
    // no equal so cannot handle
    Serial.println(F("Syntax Error - Correct Syntax is: EWn,v "));
    Serial.println(F("where n is the address, and v is the value"));
  } else {
    
    // work out the item and the location
    String loc = extraCmd.substring(0,index);
    String val = extraCmd.substring(index+1);
    byte location = loc.toInt();
    long value = val.toInt();
    
    if ( isLocationException(location) || isProtectedException(location) ) {
    //if ( isProtectedException(location) ) {  
      Serial.print(F("Cannot write to address "));
      Serial.println(location);
      return;
    }
    
    // write to eprom obeying protected status
    eepromWrite(location,value);
  } 
}

/**
 * The Flash command is used to re-initialise the firmware
 * Normall this shouldnt be needed. Only use if you need to recover defaults.
 */
void eepromInitCommand() {

    // EPROM Initialise. Resets the Eprom Values to default Values, sugest reboot after this
    eepromWrite(EEP_VERSION,0);
    
    // forces the eeprom to be re-inited
    checkEepromConfiguration();
    
    Serial.println(F("Flashed."));
}

#endif

//
// ============================================
// The main Background Task Scheduler
// ============================================
//

// A general purpose timer, and some misc constants
SimpleTimer timer = SimpleTimer();

// this does the actual work
void loopSimpleTimer() {
  timer.run();
}

//
// =================================
// STATE MACHINE ---
// =================================
//

// Inital Null State for Startup Definition of FSM
State STATE_STARTUP   = State (startupAndTransition);

// States of the Kiwi iMac FSM
State STATE_ACTIVE    = State (enterActiveMode   ,updateActiveMode   ,leaveActiveMode   );
State STATE_SLEEP     = State (enterSleepMode    ,updateSleepMode    ,leaveSleepMode    );
State STATE_POWERDOWN = State (enterPowerDownMode,updatePowerDownMode,leavePowerDownMode);
State STATE_INACTIVE  = State (enterInactiveMode ,updateInactiveMode ,leaveInactiveMode );
State STATE_POWERUP   = State (enterPowerUpMode  ,updatePowerUpMode  ,leavePowerUpMode  );

// Controlling Finitate State Manage, initial Active State
FiniteStateMachine fsm=FiniteStateMachine(STATE_STARTUP);

/**
 * Main Loop that processes the FSM contoller loop
 */
void loopFiniteStateMachine() {
  
  // Main Update Loop for The FSM
  fsm.update();
}
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

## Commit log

2014-08-09 Fixes for startup issues, Power Button Activiation
    Significant fixes in startup code with Power button simulation and
    detection code. Added significant debugging messages.
    [iMac_i5_Rev10.ino]
2014-09-21 Added Bill of Materials
    Added Bill of Materials
    [BillOf Materials1.3.xlsx]
2014-12-28 Added Brightness Menulet
    This is the complete source code for Brightness Menulet, (runs on Mac)
    that allows the brightness to be controlled (via USB) to the Arduino
    micro controller
2015-01-23 First Test of Fan RPM Code
2015-01-23 Fixes and Testing of Fan RPM Code
    [iMac_i5_Rev10.ino]
2015-01-25 Small tidyup, defined and used pin constants.
2015-01-31 Final Fixes after Debug
    [iMac_i5_Rev10.ino]
2015-01-31 Cleanup of Fan Code, Removed Redundant
2015-01-31 Fixed Issue with EEPROM writes
    [iMac_i5_Rev10.ino]
2015-01-31 More Fixes to Capacitive
    [iMac_i5_Rev10.ino]
2015-01-31 BUG FIX For fan RPMS
    [iMac_i5_Rev10.ino]
2015-02-06 Removed LED Flash Command Code
2015-02-06 Fixed ReadOnly in EPROM
    [iMac_i5_Rev10.ino]
2015-02-15 Further REV 2 Support. Still Issues
    [iMac_i5_Rev10.ino]
2015-02-15 Fixed #iffef compiler Problem
    [iMac_i5_Rev10.ino]
2015-02-17 Further Fan work and Code Cleanup.
2015-02-18 Small addition of stepped PWM change
2015-02-18 Revert "Improved System Reporting"
    This reverts commit 43092c34f74c30da4868c2d6cb2a2ff94bc2fcef.
    [iMac_i5_Rev10.ino]
2015-02-18 Fixes to capactive Code
    [iMac_i5_Rev10.ino]
2015-02-18 More simple Fixes, compatibility
    [iMac_i5_Rev10.ino]
2015-02-19 Revert 997a22c..606fe0a
    This rolls back to commit 997a22c1ea8c0d0d6c7038b4ded34150e8846562.
    [iMac_i5_Rev10.ino]
2015-02-24 Added Eagle Files
    [iMacG5-v2.brd, iMacG5-v2.sch]
2015-05-31 Feature improvement of the Arduino Code to support new Menu Command
2015-05-31 Fixed to correctly display degC in terminal
    [iMac_i5_Rev10.ino]
2015-05-31 Added Feature to turn LED on when inverter is Off.
2015-08-08 Small Minor changes for Modern Board
2015-08-09 Small Improvements and attempt to fix Fans
    [iMac_i5_Rev10.ino]

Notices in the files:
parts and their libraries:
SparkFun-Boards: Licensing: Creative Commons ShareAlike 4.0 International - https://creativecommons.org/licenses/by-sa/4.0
